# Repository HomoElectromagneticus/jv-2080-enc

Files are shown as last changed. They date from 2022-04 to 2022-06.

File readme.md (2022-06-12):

This PCBA design implements a replacement for the main "value" encoder on the Roland JV-2080 synthesizer. This is useful because the original part is no longer manufactured.

In short, this design leverages work available on mitxela.com, namely: https://mitxela.com/projects/jv1080_encoder_repair. The code shown on that page creates an elegant low-power interface between a standard rotary encoder commonly available at the time of this writing and what the JV-2080 expects. I encourage any reader here to explore that page to learn more.

You may find the necessary files to build this project for yourself on the "Releases" section of this repository page. Note that you will also need the pre-compiled binary to flash onto the ATTiny13A as well as a means to flash it. You may find the pre-compiled binary here: https://github.com/mitxela/jv1080-encoder. Pay attention to the fuse settings required for the microcontroller: 
  - high fuse byte -> 0xFF 
  - low fuse -> 0x73

These will need to be set when flashing the ATTiny13A.

For more information about the process, please visit https://homoelectromagneticus.com/projects/jv_2080_enc.php. If you try this project for yourself and run into a problem, do not hesitate to create an issue in this repository and I will do my best to help you.

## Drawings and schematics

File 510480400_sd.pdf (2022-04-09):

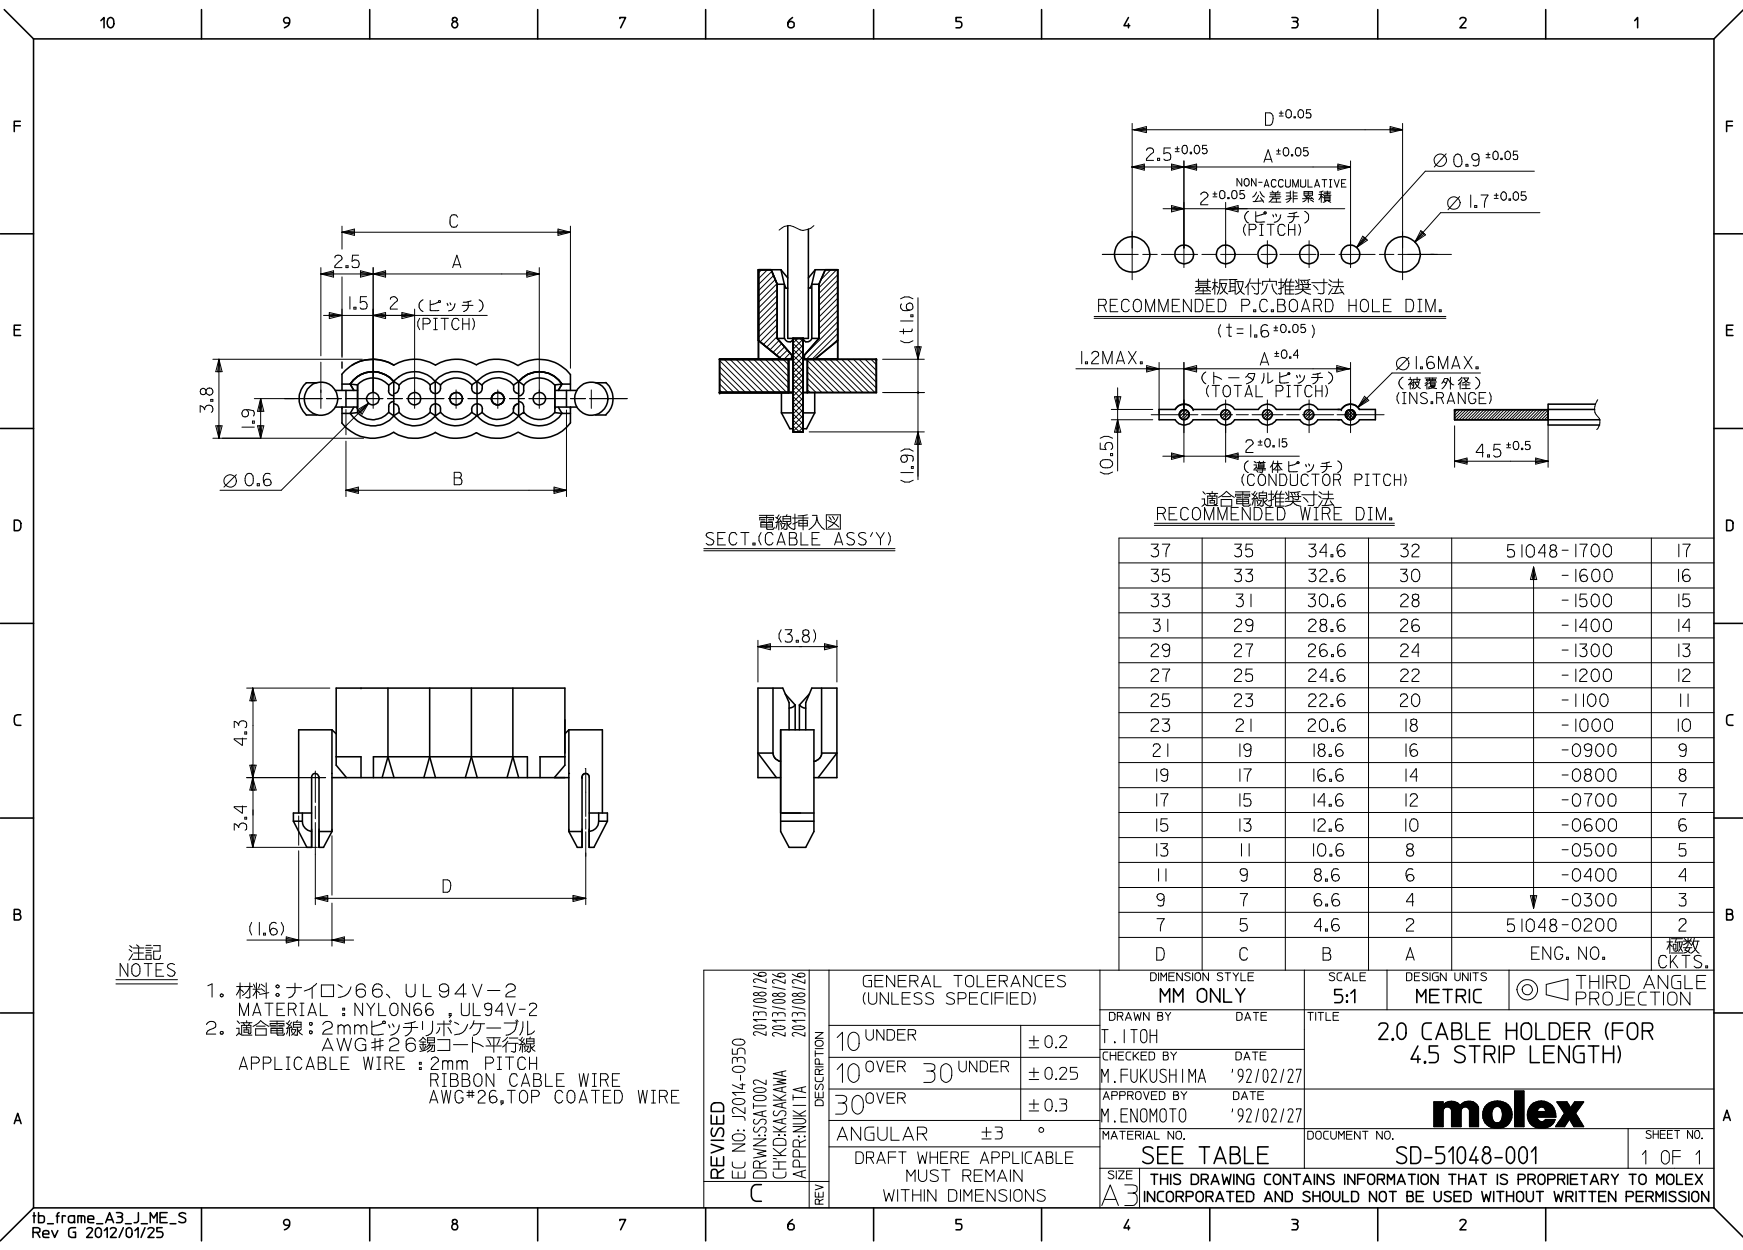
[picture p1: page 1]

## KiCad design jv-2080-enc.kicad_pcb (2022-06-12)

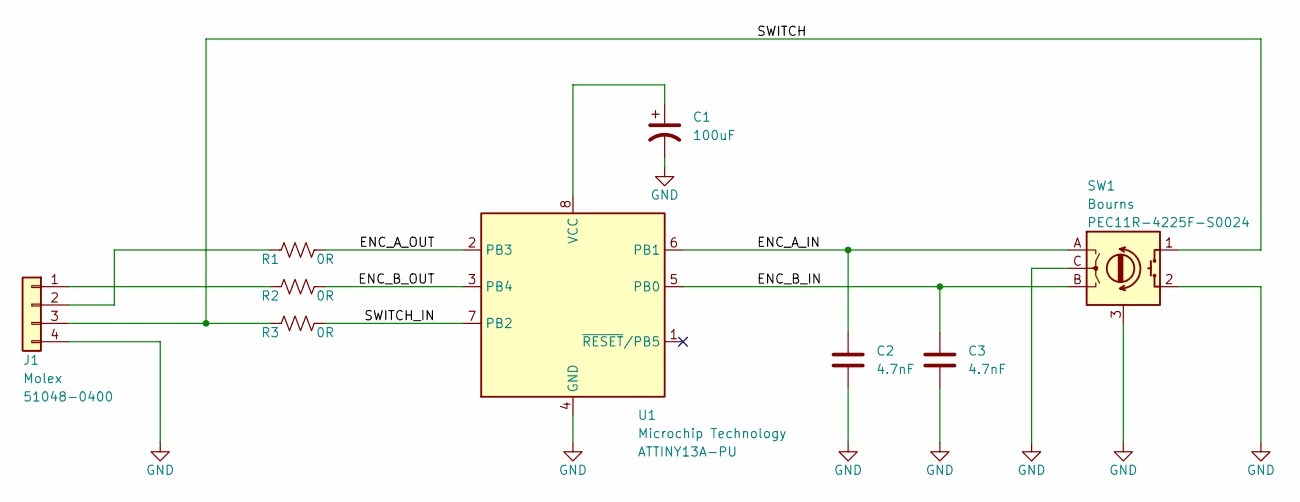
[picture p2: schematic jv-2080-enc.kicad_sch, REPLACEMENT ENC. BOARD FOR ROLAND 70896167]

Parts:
C1: 100uF; CP_Radial_D5.0mm_P2.00mm; Manuf PN UVY1E101MDD
C2, C3: 4.7nF; C_Rect_L7.0mm_W2.0mm_P5.00mm; Manuf PN R82EC1470AA50K
J1: Conn_01x04; Molex_51048-0400; Manuf PN 51048-0400
R1, R2, R3: 0R; R_Axial_DIN0207_L6.3mm_D2.5mm_P7.62mm_Horizontal
SW1: RotaryEncoder_Switch; Rotary_Encoder_Switched_PEC11R; Manuf PN PEC11R-4225F-S0024
U1: ATtiny13A-P; DIP-8_W7.62mm; Manuf PN ATTINY13A-PU

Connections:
/ENC_A_IN: C2.1, SW1.A, U1.6 (PB1)
/ENC_A_OUT: R1.2, U1.2 (PB3)
/ENC_B_IN: C3.1, SW1.B, U1.5 (PB0)
/ENC_B_OUT: R2.2, U1.3 (PB4)
/SWITCH: J1.3, R3.1, SW1.1 (S1)
/SWITCH_IN: R3.2, U1.7 (PB2)
GND: C1.2, C2.2, C3.2, J1.4, SW1.2 (S2), SW1.3 (Chassis), SW1.C, U1.4 (GND)
unnamed: C1.1, U1.8 (VCC)
unnamed: J1.1, R2.1
unnamed: J1.2, R1.1

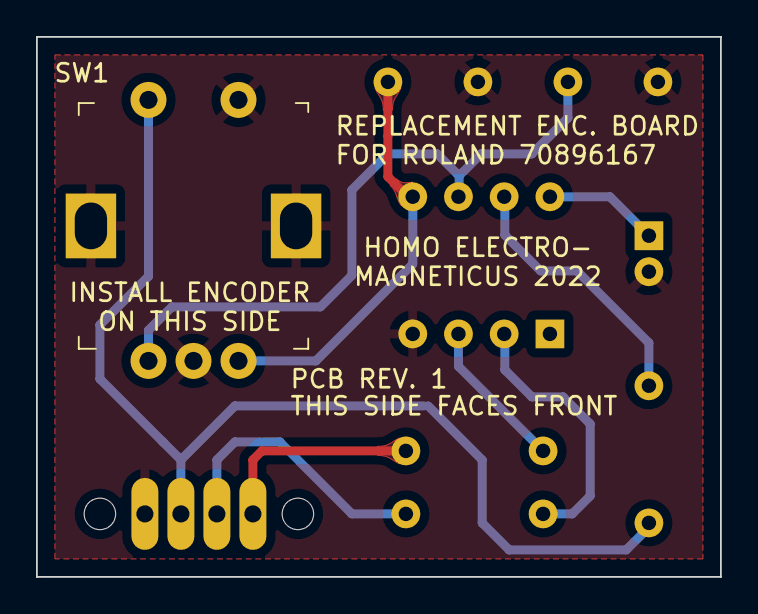
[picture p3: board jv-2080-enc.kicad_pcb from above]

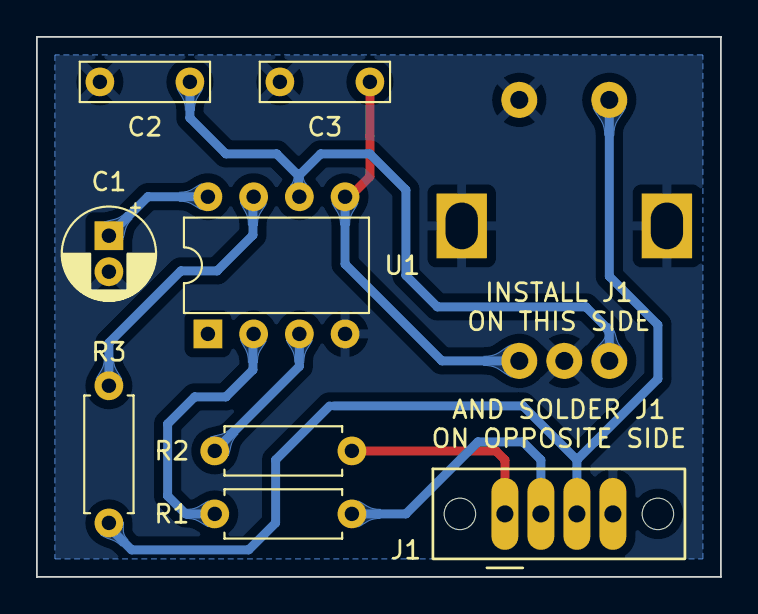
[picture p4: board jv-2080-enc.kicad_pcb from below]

Board: 2 copper layers, 38.0 x 30.0 mm, 9 parts (8 on the bottom side), 10 nets.

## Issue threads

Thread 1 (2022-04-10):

Verify design

HomoElectromagneticus, 2022-04-10:
So far, this PCBA is unverified. Once the design has been built and tested, I will close this issue.

HomoElectromagneticus, 2022-05-26:
Design verified. One change needed to resolve a problem - resolved by 7961d617c34d01570497aa6c31140d496116cc52

Closed 2022-05-26.

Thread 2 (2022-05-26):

Missing BOM

HomoElectromagneticus, 2022-05-26:
This project lacks a BOM, so how could anyone build it?

HomoElectromagneticus, 2022-06-12:
Fixed as of 3dc5a523749462067fc55838adc1954c04ee00e2 .

Closed 2022-06-12.

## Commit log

2022-04-09 initial commit of KiCAD design
    [jv-2080-enc.kicad_pcb, jv-2080-enc.kicad_sch]
2022-04-10 Rounding all the tracks and adding teardrops for fun.
    [jv-2080-enc.kicad_pcb]
2022-04-10 Moved most of the components to the other side of the PCBA to account for the much smaller body size of a modern encoder vs the original one.
    [jv-2080-enc.kicad_pcb]
2022-04-20 Re-drew the schematic to be easier to read. Tweaked the layout so that the PCB is 2mm less wide.
    [jv-2080-enc.kicad_pcb, jv-2080-enc.kicad_sch]
2022-04-21 Further schematic and layout tweaks - minor stuff
    [jv-2080-enc.kicad_pcb, jv-2080-enc.kicad_sch]
2022-04-21 Tweaked output settings to build gerbers and drills the right way.
    [jv-2080-enc.kicad_pcb]
2022-05-26 Fixed miswired encoder connection. Added helpful silkscreen text. Bumped revision number from 0 to 1.
    [jv-2080-enc.kicad_pcb, jv-2080-enc.kicad_sch]
2022-05-26 Added gerber files for production
    [jv-2080-enc-B_Cu.gbl, jv-2080-enc-B_Mask.gbs, jv-2080-enc-B_Silkscreen.gbo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]
2022-06-11 Added manufacturer and part number details to necessary circuit elements.
    [jv-2080-enc.kicad_sch]
2022-06-12 Corrected part number of the rotary encoder
    [jv-2080-enc.kicad_pcb, jv-2080-enc.kicad_sch]
2022-06-12 Added info about microcontroller fuse settings
